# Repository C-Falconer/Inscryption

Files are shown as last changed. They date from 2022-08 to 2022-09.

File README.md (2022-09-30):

# Interactive RFID Card Game
### Based on the game Inscryption by Daniel Mullins
---
#### So, here's the project...

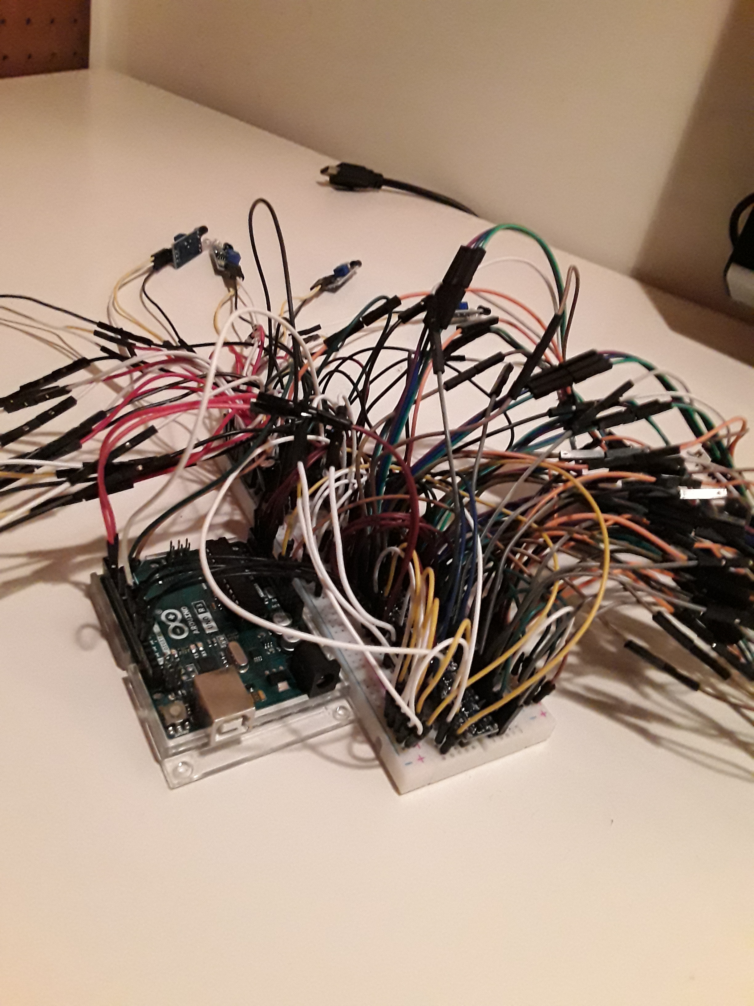
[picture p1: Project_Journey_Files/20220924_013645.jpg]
Wire Monster Final Phase
 <a href="http://www.youtube.com/watch?feature=player_embedded&v=RWWOy5Cf8dE
" target="_blank">Python Game</a>

#### ... but we might want to back up first.

From May-August (except for some future presentation), 2022 I decided to start a project. This project uses 10 MFRC522 RFID tags and an Arduino to simulate the game Inscryption through interacting with a Python program using Pygame. 
The Python program itself uses threading to be able to talk to the Serial port while simultaneously run event checking. The Arduino code helps to handle the incoming Serial information of the RFID readers along with the IR Sensors. The Arduino code is also responsible for handling the shift registers and multiplexer. But before we get to the project journey, let's get some technical details out of the way.

## Parts Used:
* 10  MFRC522 RFID Readers
* 20  RFID Tags
* 10  IR Sensors
* 2   Daisy Chained CD74HC165 Shift Registers
* 1   CD74HCT4051e 8:1 Multiplexer
* 4   4 Channel Bidirectional Logic Level Converters
* 10  10k Resistors
* 3   2k Resistors
* 1   100uF 50V Electrolytic Capacitor
* 1   Arduino Uno R3 (Connected to a device running Python)
* 1   Breadboard
* Plenty of Wires

## Libraries Used:
* pygame
* pyautogui (size)
* os (listdir)
* sys (exit)
* serial (Serial)
* threading (Thread)
* PIL (Image)
* random (uniform)
* math (floor)
* ShiftIn - Arduino
* SPI - Arduino
* MFRC522 - Arduino

#### Other parts include that of a table to act as a placemat (next step) and a custom 3D printed card sleeve. 
---
# Project Journey
**5/20** - The project first started with purchasing the MFRC522 RFID Readers, Bidirectional Logic Level Converters, and Soldering Tools. While waiting, I decided to design a 3D model of the cards. 

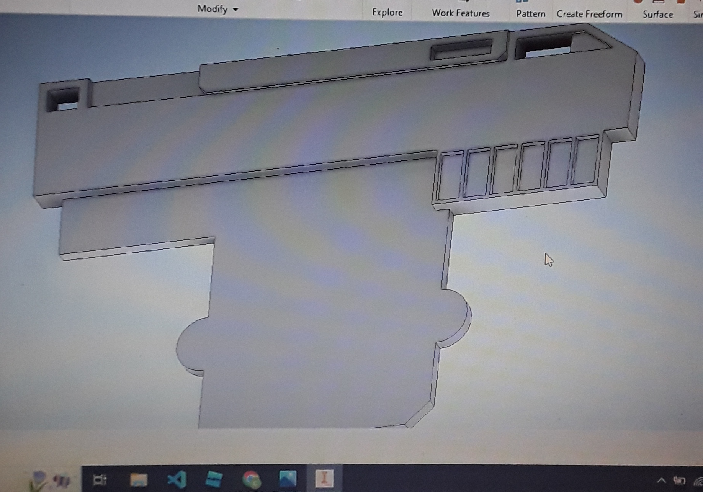
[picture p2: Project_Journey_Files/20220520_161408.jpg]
Card Top 3D
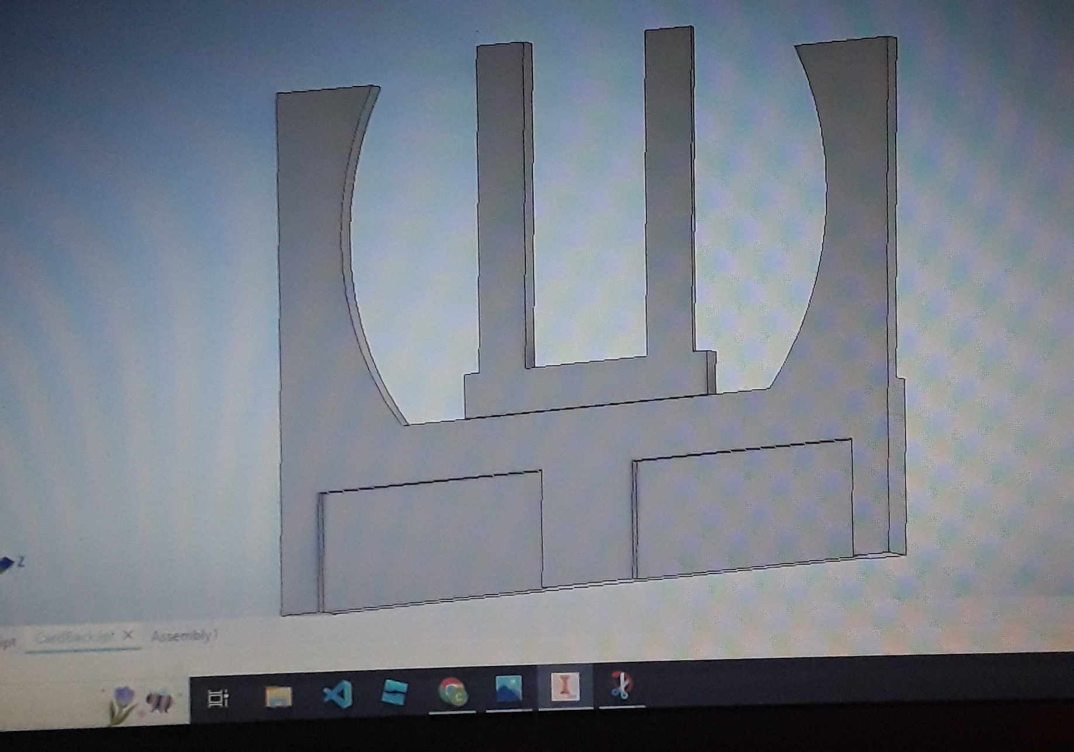
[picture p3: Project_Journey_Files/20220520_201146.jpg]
Card Bottom 3D
 

**5/21** - With the items arriving (Logic Level Converters shown later), I needed to decide what to do next. 

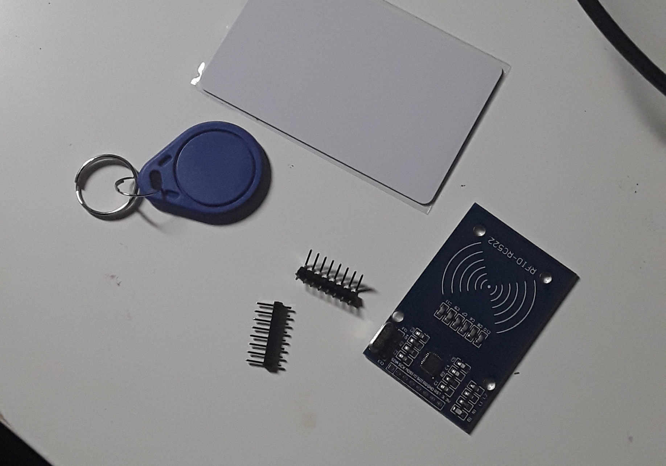
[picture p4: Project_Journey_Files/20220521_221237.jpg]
RFID Reader
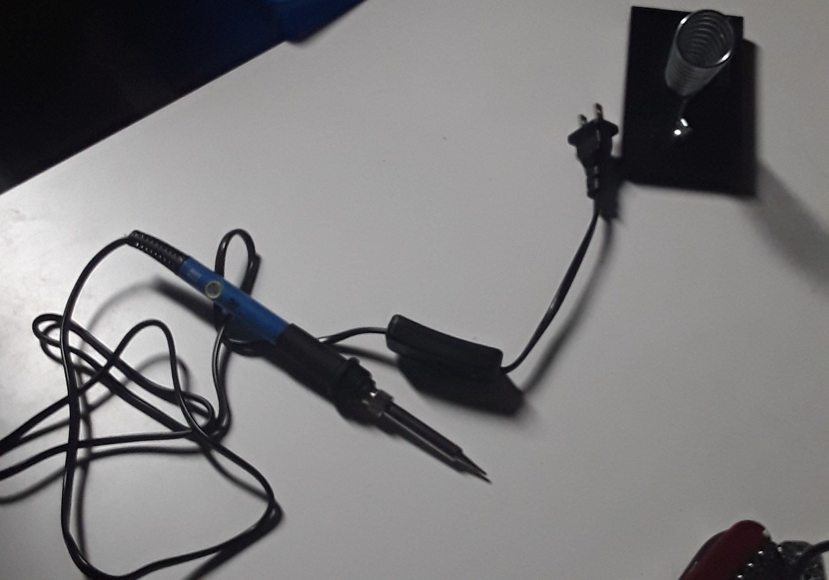
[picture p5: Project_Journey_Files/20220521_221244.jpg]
Soldering Tools
 

**5/26** - I decided to still focus a little more on the 3D model and make an assembly.

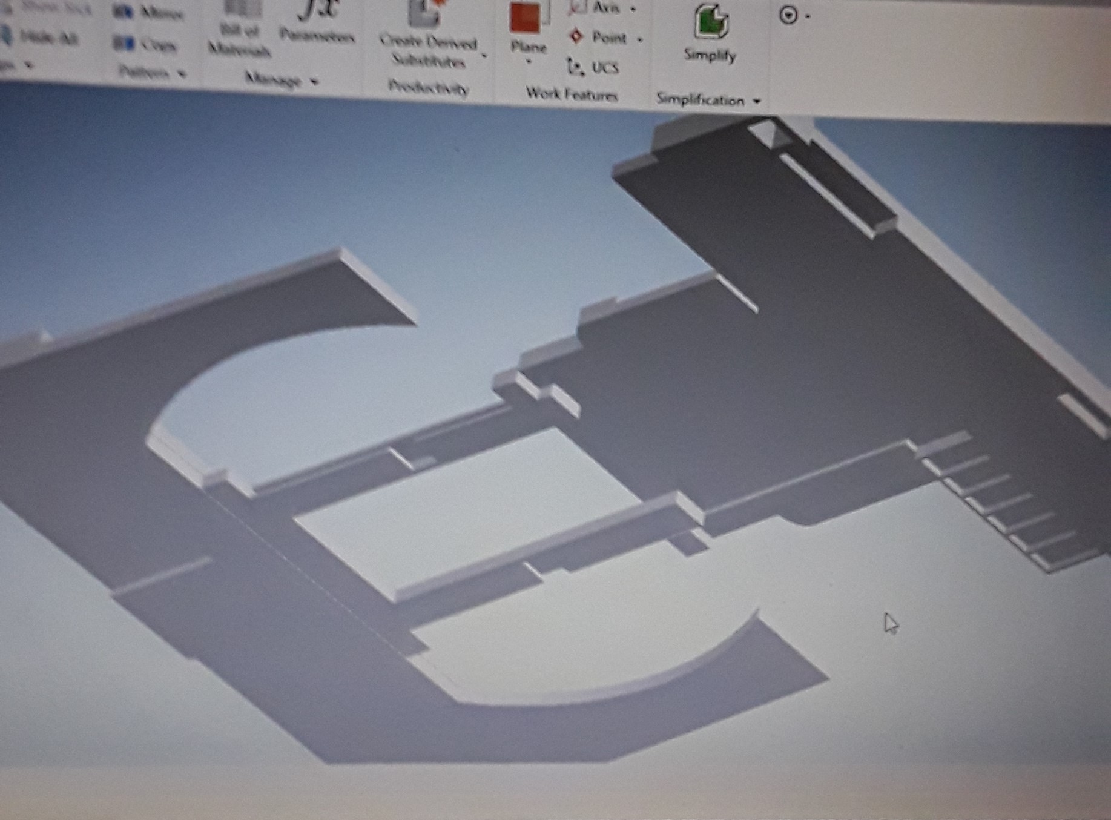
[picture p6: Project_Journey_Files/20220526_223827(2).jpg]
Card Extended Assembly
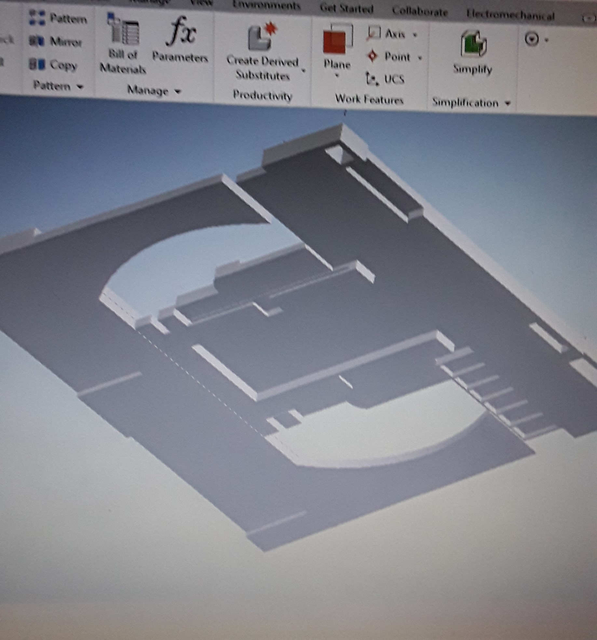
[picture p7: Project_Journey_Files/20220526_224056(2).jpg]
Card Compressed Assembly
 

**5/28** - Next up was to print out my first prototype. Sadly though, my floor wasn't level so it wasn't able to print on my 3D printer.

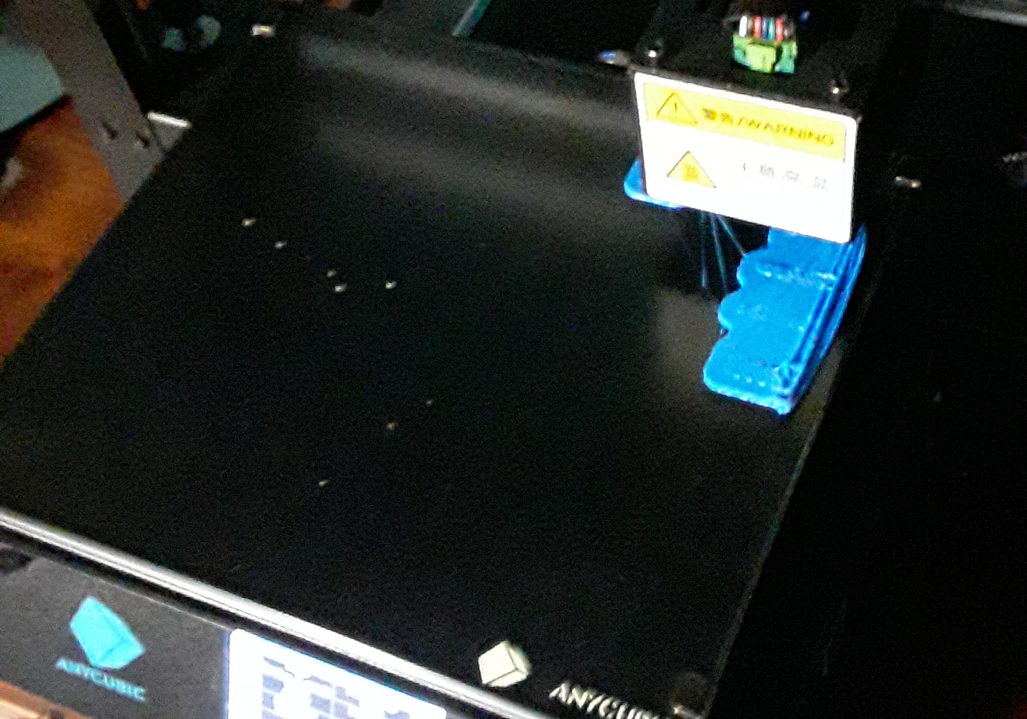
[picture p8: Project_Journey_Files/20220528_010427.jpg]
3D Print
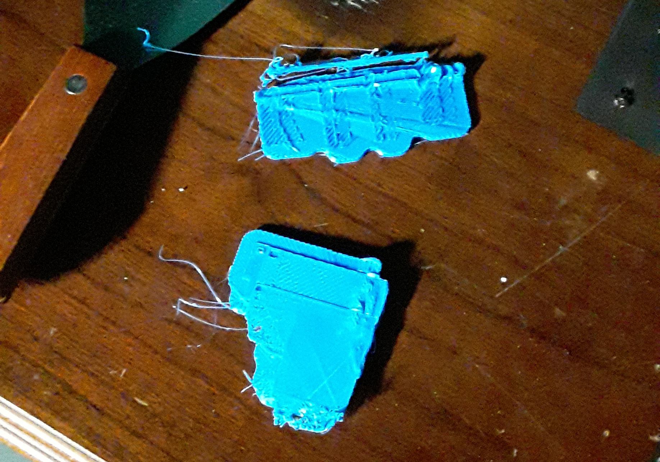
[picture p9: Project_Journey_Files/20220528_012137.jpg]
3D Print Fail
 

**6/2** - Deciding to move on for the time being, I decided to move to the soldering. I had never soldered before, so I set up a station in my backyard, and with plenty of video tutorials watched, went ahead and soldered one of the Bidirectional Logic Level Converters. I decided to solder these before the RFID Readers in order not to mess up the more expensive Readers.

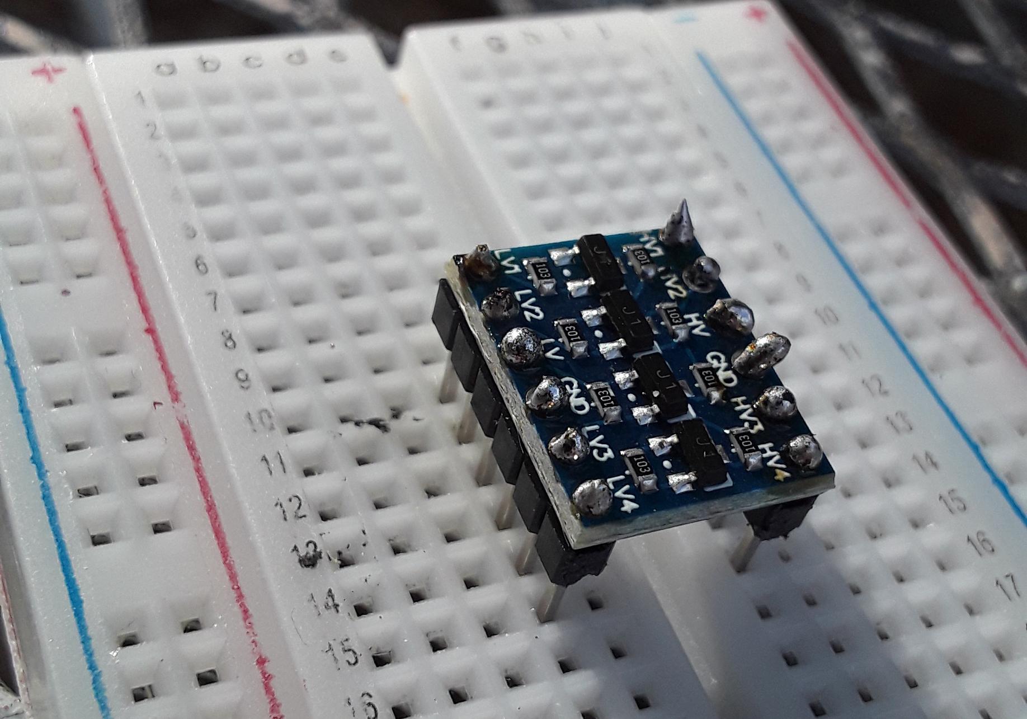
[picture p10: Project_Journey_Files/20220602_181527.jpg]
First Solder


...Soon after I went to testing the connections I had just soldered. It was a bit difficult at first to figure out how to work the Level Converter, but it would take a bit more time before I became knowledgeable enough to properly use them.

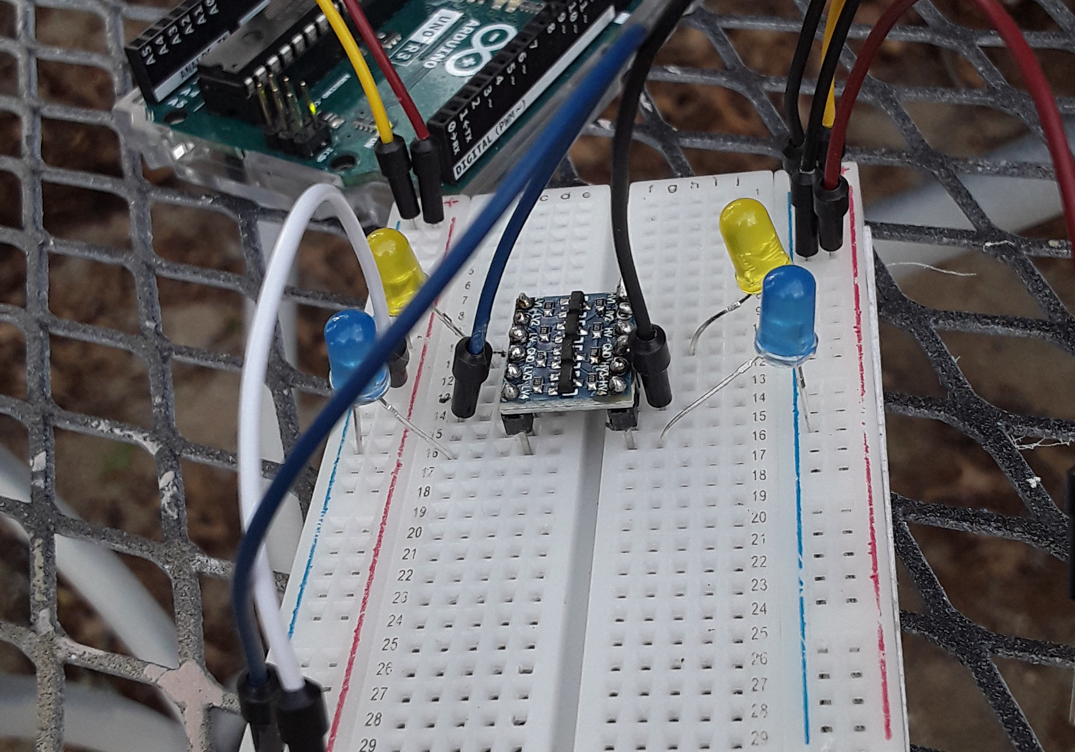
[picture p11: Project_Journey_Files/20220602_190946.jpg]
LLC Test


**6/4** - With my first round of equipment arriving, my full set up was looking more and more chaotic by the second (the Lead solder at the top right was handled with considerably more care in the future). 

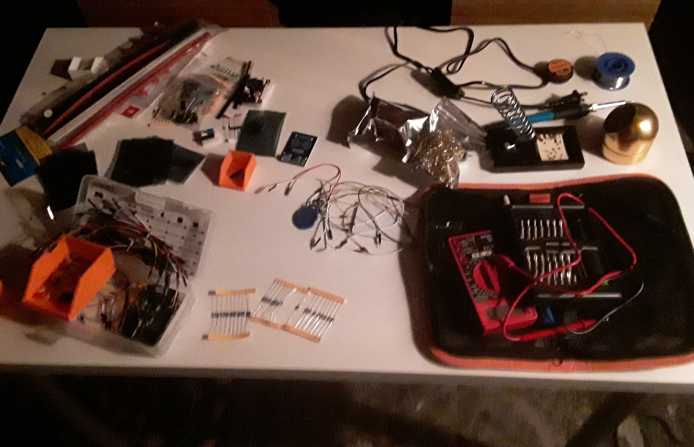
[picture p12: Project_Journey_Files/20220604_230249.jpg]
Equipment Round 1


**6/8** - I eventually decided to redo the 3D printing on the cards, as I had found better resources for reference online. I had also developed better techniques for modeling accurately.

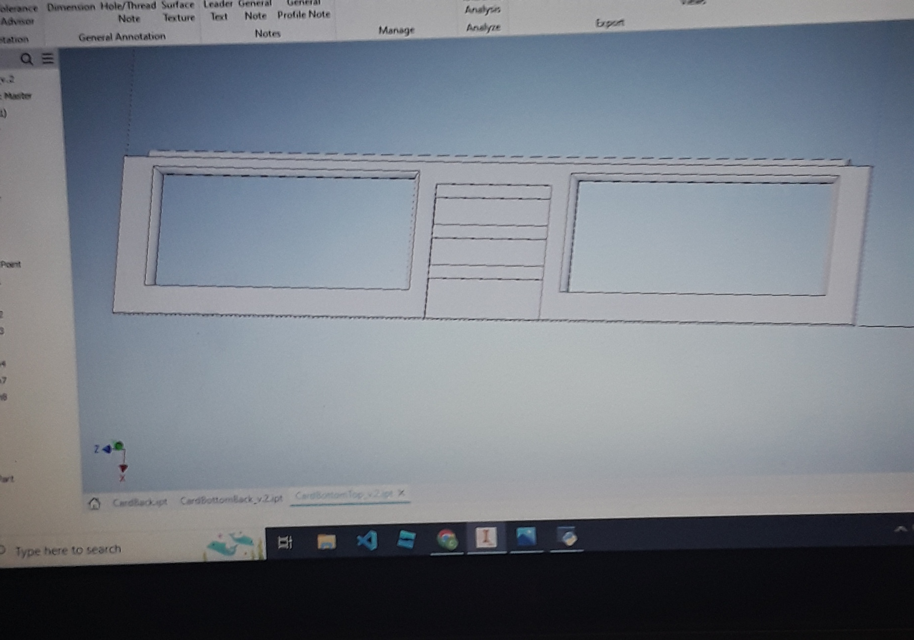
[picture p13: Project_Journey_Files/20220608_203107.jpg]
New Card Bottom 3D


**6/16** - Around this time I got a full time job unrelated to the project, so the consistency of work intervals was low. However, it became a mental escape for me as I enjoyed the problem solving and multistep processes. I went and modeled more of the card and went to print it at my University, where I had access to better printers.

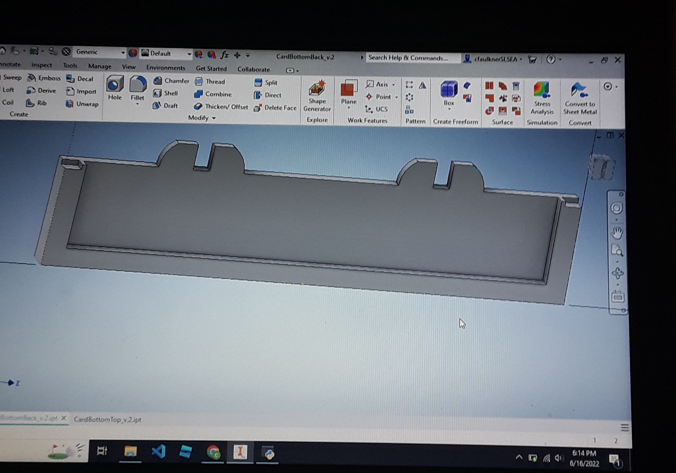
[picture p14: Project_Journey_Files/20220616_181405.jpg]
Card Bottom Back
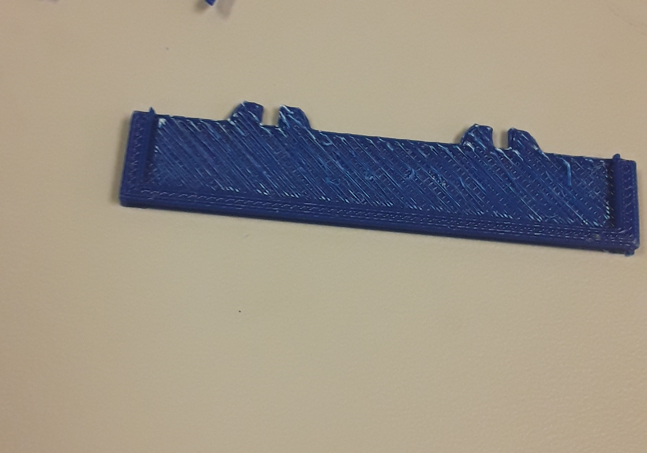
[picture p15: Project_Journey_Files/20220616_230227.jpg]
Better 3D Print
 

...Sadly during the process, I bent the smaller from plate while removing it from supports. I was significantly more careful in the future with this, however the low thickness caused them to often bend.

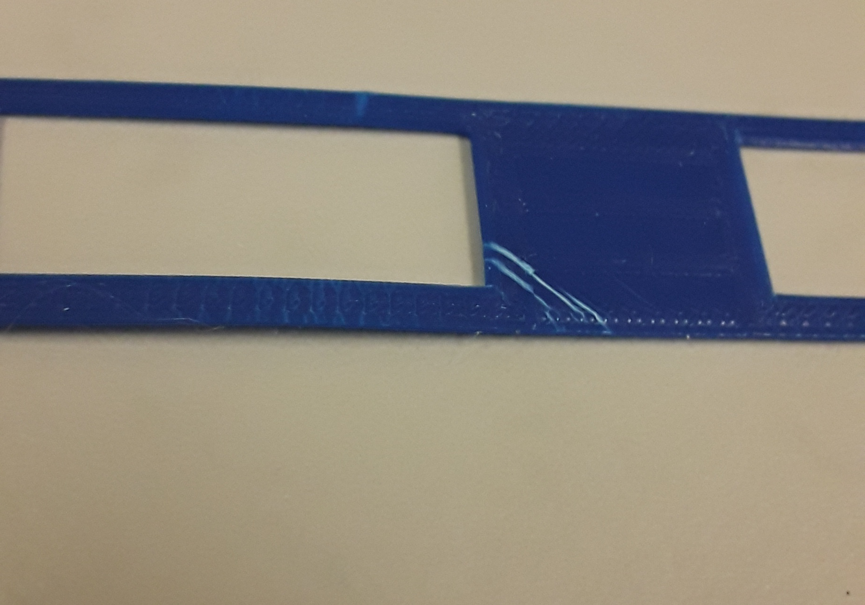
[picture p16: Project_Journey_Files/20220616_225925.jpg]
Bent 3D Piece


**6/22** - Soon enough I tried connecting the RFID Reader to my Arduino through 2 Logic Level Converters. There was a lot of difficulty getting the specifics to work, but getting it to work with the Logic Level Converters helped the integrity of the RFID Readers stay quality.

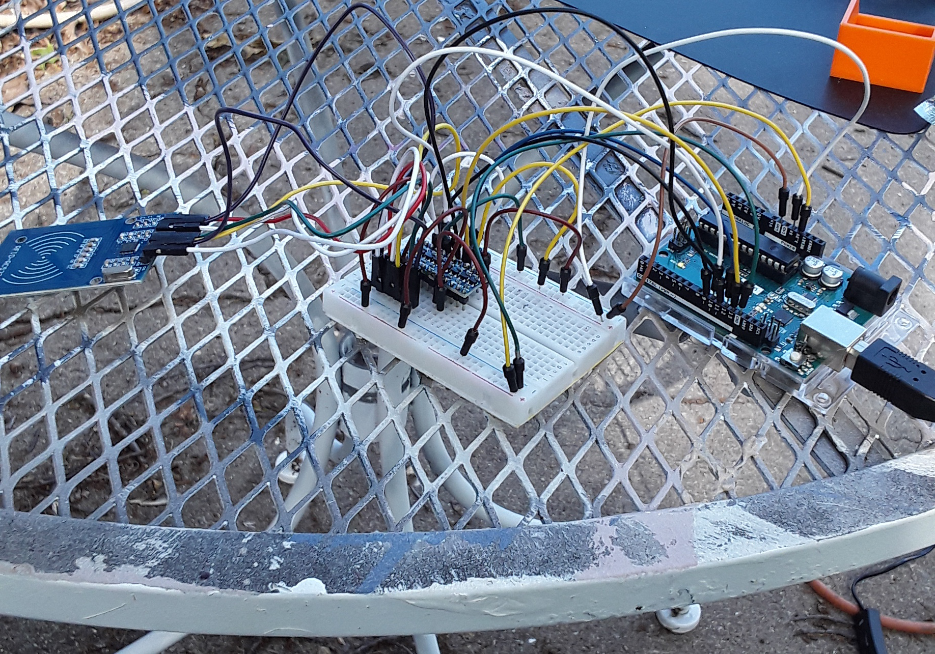
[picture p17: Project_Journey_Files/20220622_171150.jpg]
LLC with RFID


...My soldering station had also had improvements from me wanting to stay as safe as I could while working with it. In the future, I will probably avoid LED solder all together, as the potential of micro accumulations are worrying.

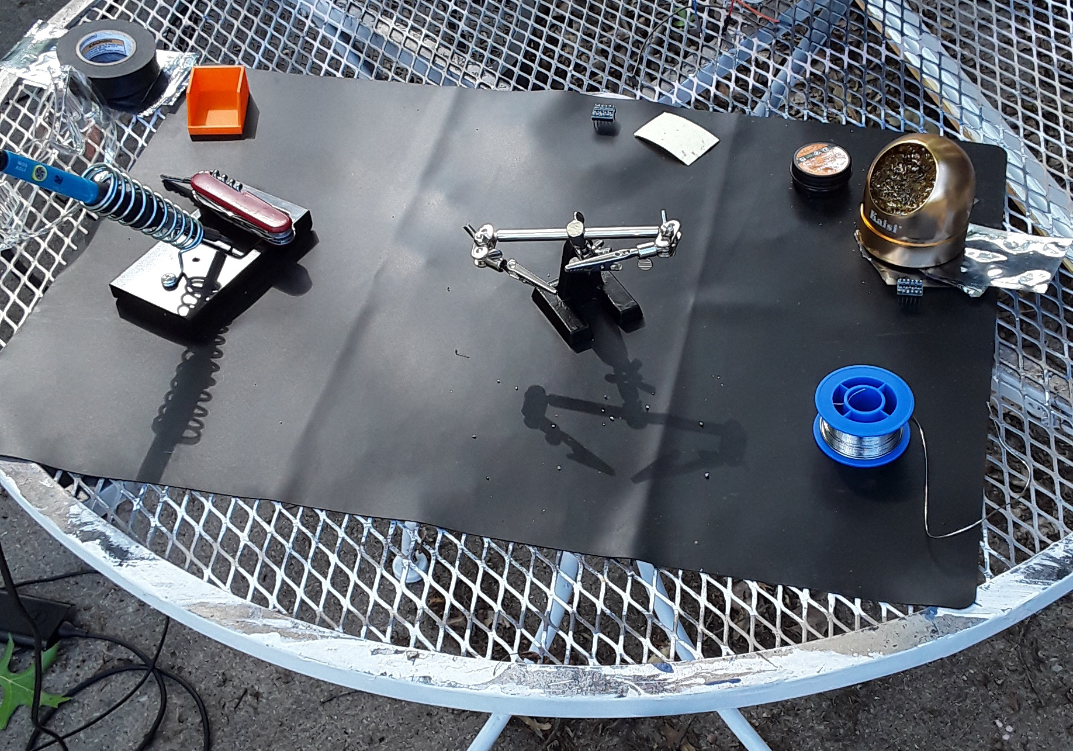
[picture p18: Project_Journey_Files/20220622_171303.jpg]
Soldering Setup


**6/23** - Using the setup from before, I was able to connect Python, through the serial port, to the Arduino and respond to the cards read.

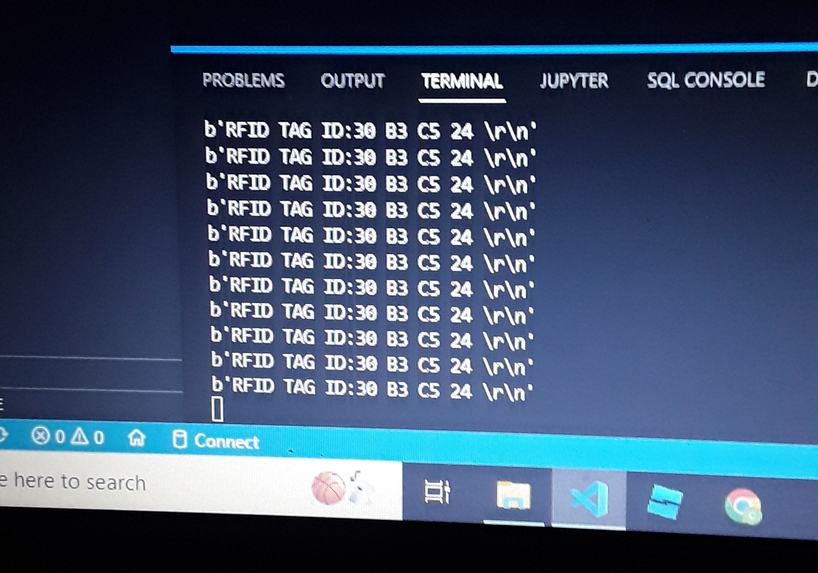
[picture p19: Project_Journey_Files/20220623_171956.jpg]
Python Read


**6/25** - One of the biggest issues for me, throughout the beginning of the project, was figuring out how to make multiple RFID Readers activate how I wanted to. One way I attempted to do this was by pouring through the functions of the MFRC522 Arduino library. While unsuccessful, it was helpful to have to learn how the inner parts were working. 

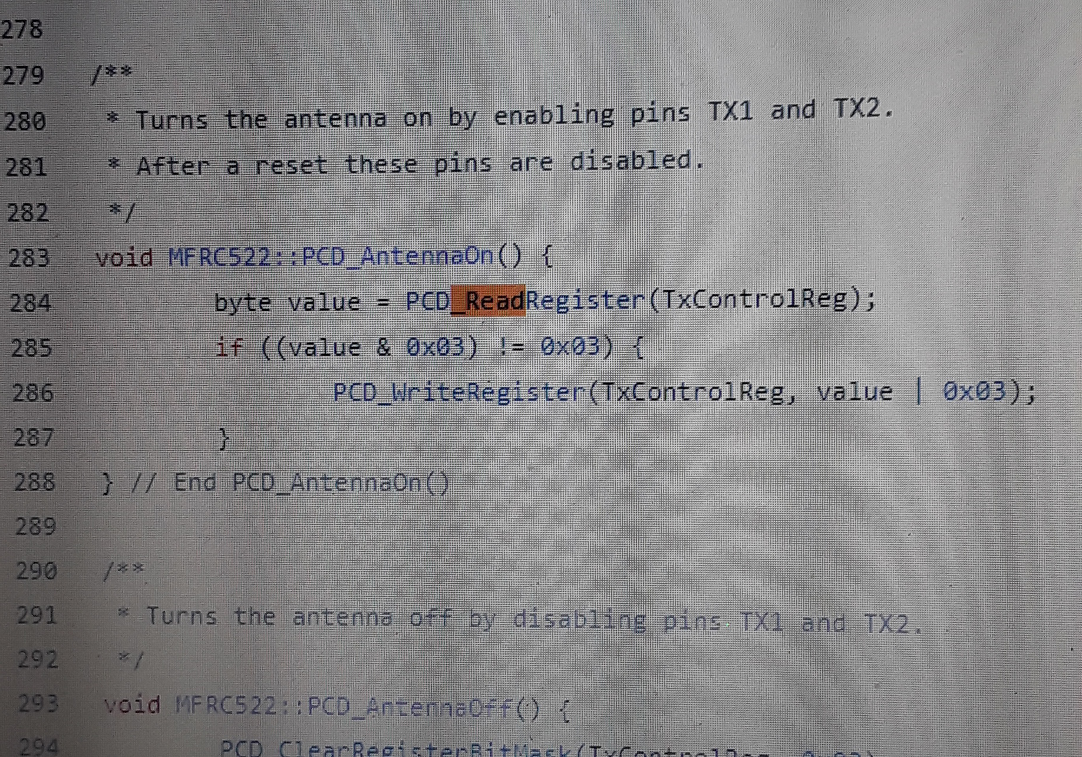
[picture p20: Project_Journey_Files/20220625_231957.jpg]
MFRC522 Library Functions


...

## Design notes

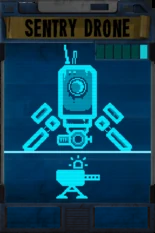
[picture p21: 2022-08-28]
Code/Python/Resources/Images/Cards/Sentry_Drone.png

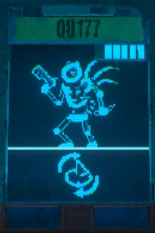
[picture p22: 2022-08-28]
Code/Python/Resources/Images/Cards/QU177.png

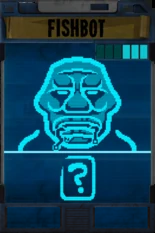
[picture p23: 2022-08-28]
Code/Python/Resources/Images/Cards/Fishbot.png

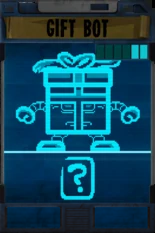
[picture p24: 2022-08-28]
Code/Python/Resources/Images/Cards/Gift_Bot.png

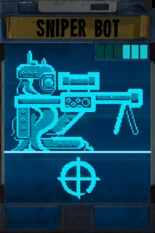
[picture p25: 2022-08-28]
Code/Python/Resources/Images/Cards/Sniper_Bot.png

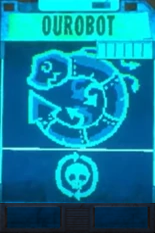
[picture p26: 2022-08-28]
Code/Python/Resources/Images/Cards/Ourobot.png

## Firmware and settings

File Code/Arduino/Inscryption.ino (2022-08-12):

#include <ShiftIn.h>
#include <SPI.h>
#include <MFRC522.h>

#define SCK 13
#define MISO 12
#define MOSI 11
#define MUX 10
#define RST 9
//8
//7
#define CP 6
#define _Q7 5
//4
#define MFRC9 3
#define MFRC10 2
#define s0 A0
#define s1 A1
#define s2 A2
#define _PL A3
#define _CE A4
//A5

int selectionLines[3] = {s0, s1, s2};

MFRC522 mfrc522(MUX, RST);
MFRC522 mfrc522_9(MFRC9, RST);
MFRC522 mfrc522_10(MFRC10, RST);

MFRC522 mfrc522s[3] = {mfrc522, mfrc522_9, mfrc522_10};

ShiftIn<2> shift;

byte IRValues[10] = {0, 0, 0, 0, 0, 0, 0, 0, 0, 0};
byte oldID[4];

void setup() {
  // put your setup code here, to run once:
  Serial.begin(9600);
  while(!Serial);
  SPI.begin();
  mfrc522.PCD_Init();
  mfrc522_9.PCD_Init();
  mfrc522_10.PCD_Init();
  pinMode(CP, OUTPUT);
  pinMode(_Q7, INPUT);
  pinMode(s0, OUTPUT);
  pinMode(s1, OUTPUT);
  pinMode(s2, OUTPUT);
  pinMode(_PL, OUTPUT);
  pinMode(_CE, OUTPUT);
  //mfrc522.PCD_DumpVersionToSerial();
  //mfrc522.PICC_DumpToSerial(&(mfrc522.uid));
  lineSelectMux(0);
  //tester();
  shift.begin(_PL, _CE, _Q7, CP);
}

int current_MFRC = 0;
int muxSelected = 0;
void loop() {
  if(shift.update()) {
    displayValues();
  }
  if(mfrc522s[current_MFRC].PICC_IsNewCardPresent() && mfrc522s[current_MFRC].PICC_ReadCardSerial()) {
    if(!isSameID()) {
      Serial.print(muxSelected);
      dump_byte_array(mfrc522s[current_MFRC].uid.uidByte, mfrc522s[current_MFRC].uid.size);
      Serial.println();
    }
  }
  delay(200);
}

//RFID
bool isSameID() {
  bool sameOld = true;
  for (int i = 0; i < mfrc522s[current_MFRC].uid.size; i++) {
    if (mfrc522s[current_MFRC].uid.uidByte[i] != oldID[i]) {
      sameOld = false;
    }
    oldID[i] = mfrc522.uid.uidByte[i];
  }
  return sameOld;
}

//Shift Register
void pulsePL() {
  digitalWrite(_PL, LOW);
  delayMicroseconds(5);
  digitalWrite(_PL, HIGH);
  delayMicroseconds(5);
}

byte getData165() {
  digitalWrite(CP, HIGH);
  digitalWrite(_CE, LOW);
  byte incoming = shiftIn(_Q7, CP, LSBFIRST);
  digitalWrite(_CE, HIGH);
  return incoming;
}

void displayValues() {
  for(int i = 0; i < shift.getDataWidth(); i++)
    //Serial.print(shift.state(i)); // get state of button i
    if(i < 2) {
      if(IRValues[i + 8] != shift.state(i)) {
//        Serial.print(i + 8);
//        Serial.print(" ");
//        Serial.println(shift.state(i));
        if(shift.state(i) == 1) {
          lineSelectMux(i + 8);
        }
      }
      IRValues[i + 8] = shift.state(i);
    } else if(i > 7) {
      if(IRValues[i - 8] != shift.state(i)) {
//        Serial.print(i - 8);
//        Serial.print(" ");
//        Serial.println(shift.state(i));
        if(shift.state(i) == 1) {
          lineSelectMux(i - 8);
        }
      }
      IRValues[i - 8] = shift.state(i);
    }
}

//Multiplexer
void lineSelectMux(int num) {
  if(num > 9 || num < 0) {
    return;
  }
  muxSelected = num;
  if(num == 8) {
    mfrc522_9.PCD_Init();
    current_MFRC = 1;
    return;
  } else if(num == 9) {
    mfrc522_10.PCD_Init();
    current_MFRC = 2;
    return;
  }
  for(int i = 0; i < 3; i++) {
    digitalWrite(selectionLines[i], num % 2);
    num /= 2;
  }
  current_MFRC = 0;
  mfrc522.PCD_Init();
}

//Extra Functions
void dump_byte_array(byte * buffer, byte bufferSize) {
  for (byte i = 0; i < bufferSize; i++) {
    Serial.print(buffer[i] < 0x10 ? " 0" : " ");
    Serial.print(buffer[i], HEX);
  }
}

void tester() {
  byte tmp;
  mfrc522.PCD_WriteRegister(mfrc522.TPrescalerReg, 0x3E);   // TPreScaler = TModeReg[3..0]:TPrescalerReg, ie 0x0A9 = 169 => f_timer=40kHz, ie a timer period of 25�s.
  tmp = mfrc522.PCD_ReadRegister(mfrc522.TPrescalerReg);
  Serial.print("TPrescalerReg ");
  Serial.println(tmp, HEX);
  
  mfrc522.PCD_WriteRegister(mfrc522.TReloadRegH, 0);    // Reload timer with 0x3E8 = 1000, ie 25ms before timeout.
  tmp = mfrc522.PCD_ReadRegister(mfrc522.TReloadRegH);
  Serial.print("TReloadRegH ");
  Serial.println(tmp, HEX);
  
  mfrc522.PCD_WriteRegister(mfrc522.TReloadRegL, 30);
  tmp = mfrc522.PCD_ReadRegister(mfrc522.TReloadRegL);
  Serial.print("TReloadRegL ");
  Serial.println(tmp, HEX);
  

  mfrc522.PCD_WriteRegister(mfrc522.ModeReg, 0x3D);   // Default 0x3F. Set the preset value for the CRC coprocessor for the CalcCRC command to 0x6363 (ISO 14443-3 part 6.2.4)
  tmp = mfrc522.PCD_ReadRegister(mfrc522.ModeReg);
  Serial.print("ModeReg ");
  Serial.println(tmp, HEX);
  
  tmp = mfrc522.PCD_ReadRegister(mfrc522.VersionReg);
  Serial.print("VersionReg ");
  Serial.println(tmp, HEX);

  
  
  mfrc522.PCD_Init();   // Init MFRC522
}

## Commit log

2022-08-08 Included Fritzing diagram and C++ Arduino code.
    [Inscryption.fzz]
2022-08-08 Organized Folders
    [Inscryption.fzz, pyvenv.cfg]
2022-08-11 Inscryption_Game added card UI. Insert with # keys
    [pyvenv.cfg]
2022-08-12 Communicates with IR Sensors and MFRCs. It works!
2022-08-13 Added RFID tags, pics, and game system with combat
    [CardStats.csv]
2022-08-19 Rotated Cards|Background|Card Slots|Attack Turns
2022-08-23 Added some Sigil Support + Enhanced custom input.
    [CardStats.csv]
2022-08-28 Added more sigils. Glitch:Sniper nullifies latches
    [CardStats.csv]
